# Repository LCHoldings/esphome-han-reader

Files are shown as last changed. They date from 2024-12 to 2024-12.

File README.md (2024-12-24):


[][contributors-url] [][forks-url] [][stars-url] [][issues-url]

<!-- PROJECT LOGO -->
<br />
<div align="center">
  <a href="https://github.com/lcholdings/esphome-han-reader">
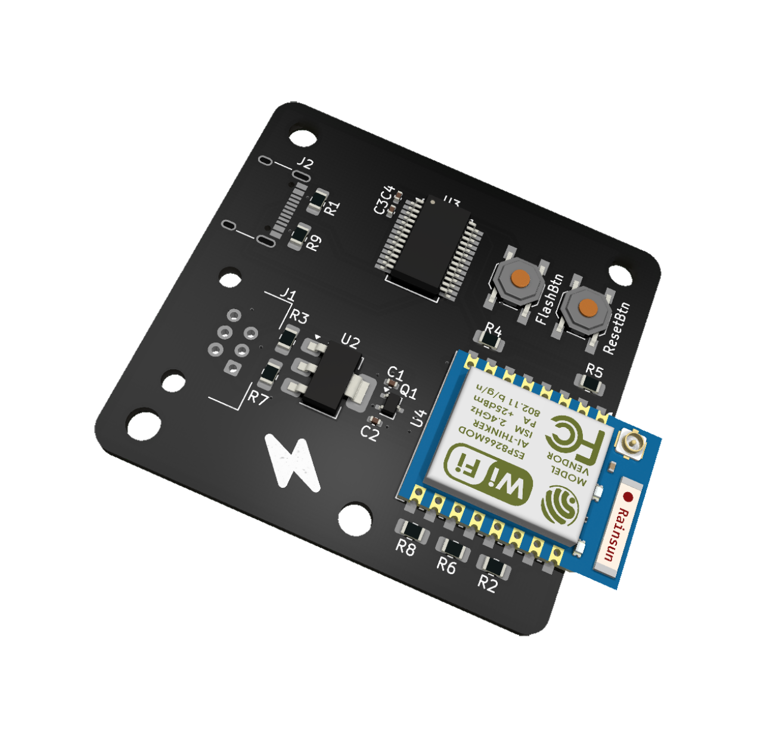
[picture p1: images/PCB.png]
    
  </a>

  <h3 align="center">ESP Home HAN Reader</h3>
  <p align="center">
    Get your power usage in realtime with extreme detail using the HAN-port.
    <br />
    <a href="https://github.com/hackclub/OnBoard/pull/1363">OnBoard PR</a>
    ·
    <a href="https://github.com/LCHoldings/esphome-han-reader/issues/new?labels=bug&template=bug-report---.md">Report Bug</a>
    ·
    <a href="https://github.com/LCHoldings/esphome-han-reader/fork">Fork Project</a>
  </p>
</div>

<!-- ABOUT THE PROJECT -->
## 📝 About The Project

In Sweden and Norway afaik we have a port on our electrical meters called the [HAN-port](https://github.com/u9n/hanporten) (Home Area Network), with this port you can get details about your power usage in almost realtime and with extreme detail compared to alternatives. I use Home Assistant in my home and we recently got our electrical meter replaced with one that has a HAN-port so I saw that as an perfect opportunity to learn some stuff and have fun.

<p align="right">(<a href="#readme-top">back to top</a>)</p>

### 🛠️ Made using

This section contains some of the most notable tools/libraries used in this project.

* 
* 

<p align="right">(<a href="#readme-top">back to top</a>)</p>

<!-- ROADMAP -->
## 🗺️ Roadmap

- [X] 🚢 Release project
- [X] 🖌️ Make ground fill
- [ ] 🤏 More compact design
- [ ] 📦 3D Printable Case
- [ ] 📡 Mouting for external antenna

<p align="right">(<a href="#readme-top">back to top</a>)</p>

<!-- CONTRIBUTING -->
## ⛑️ Contributing

Contributions are what make the open source community such an amazing place to learn, inspire, and create. Any contributions you make are **greatly appreciated**.

If you have a suggestion that would make the portfolio better, please fork the repo and create a pull request. You can also simply open an issue with the tag "enhancement".
Don't forget to give the project a star! Thanks!

1. Fork the Project
2. Change the project and add your files or changes (`git add *`)
3. Commit your Changes (`git commit -m 'Feat | Added XXXX to the XXX'`)
4. Push to the Branch (`git push`)
5. Open a Pull Request

### 🏆 Top contributors:

<a href="https://github.com/LCHoldings/esphome-han-reader/graphs/contributors">
  contrib.rocks image
</a>

<p align="right">(<a href="#readme-top">back to top</a>)</p>

<!-- CONTACT -->
## 💌 Contact

Lazyllama - [@Lazyllamaa](https://discord.com/users/754965470888722484) - me@lazyllama.xyz

Project Link: [https://github.com/lcholdings/esphome-han-reader](https://github.com/lcholdings/esphome-han-reader)

<p align="right">(<a href="#readme-top">back to top</a>)</p>

<!-- ACKNOWLEDGMENTS -->
## 🌟 Acknowledgments

Thanks to the following people for their help and inspiration:

* [Readme Template](https://github.com/othneildrew/Best-README-Template)
* [OnBoard](https://hackclub.com/onboard/)
* [Cyber](https://github.com/cyberdev-tech)
* [Hack Club](https://hackclub.com)
* [ESP Home P1 Reader](https://github.com/psvanstrom/esphome-p1reader)
<p align="right">(<a href="#readme-top">back to top</a>)</p>

<!-- MARKDOWN LINKS & IMAGES -->
<!-- https://www.markdownguide.org/basic-syntax/#reference-style-links -->
[contributors-shield]: https://img.shields.io/github/contributors/lcholdings/esphome-han-reader.svg?style=for-the-badge
[contributors-url]: https://github.com/lcholdings/esphome-han-reader/graphs/contributors
[forks-shield]: https://img.shields.io/github/forks/lcholdings/esphome-han-reader.svg?style=for-the-badge
[forks-url]: https://github.com/lcholdings/esphome-han-reader/network/members
[stars-shield]: https://img.shields.io/github/stars/lcholdings/esphome-han-reader.svg?style=for-the-badge
[stars-url]: https://github.com/lcholdings/esphome-han-reader/stargazers
[issues-shield]: https://img.shields.io/github/issues/lcholdings/esphome-han-reader.svg?style=for-the-badge
[issues-url]: https://github.com/lcholdings/esphome-han-reader/issues

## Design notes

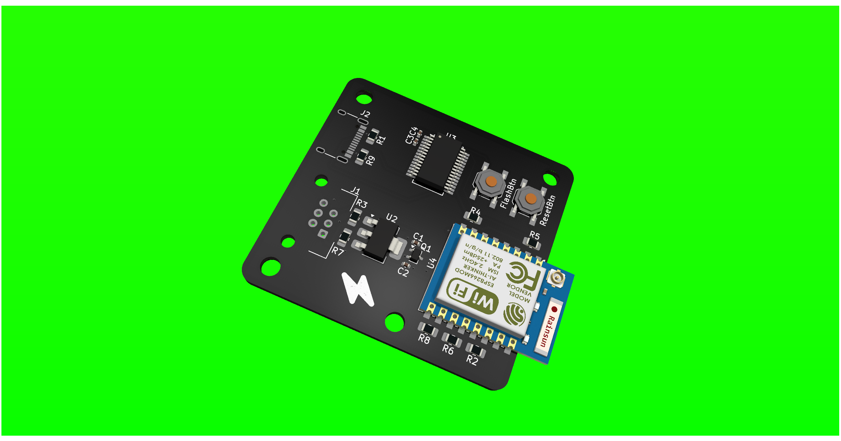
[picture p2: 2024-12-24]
esphome-han-reader.png

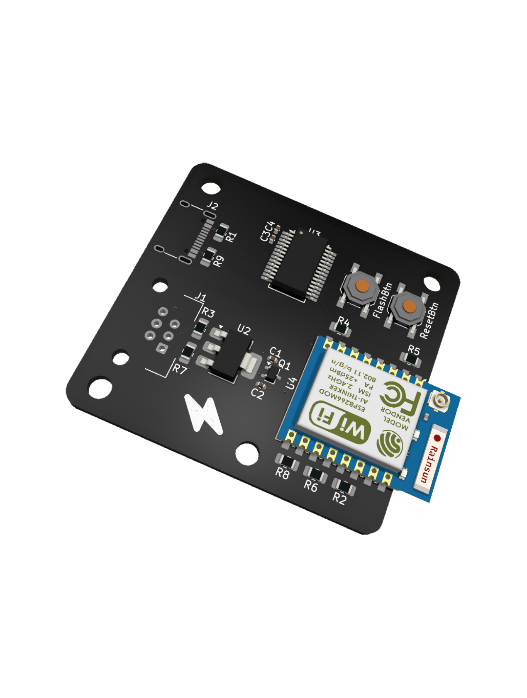
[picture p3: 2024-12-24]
images/highseas.png

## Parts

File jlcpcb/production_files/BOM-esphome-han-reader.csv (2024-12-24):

Comment | Designator | Footprint | LCSC | Quantity
0.1 µF | C3,C4 | C_0402_1005Metric | C1525 | 2
10K | R2,R4,R5,R6,R7,R8 | R_0805_2012Metric_Pad1.20x1.40mm_HandSolder | C17414 | 6
4K7 | R3 | R_0805_2012Metric_Pad1.20x1.40mm_HandSolder | C17673 | 1
5K1 | R1,R9 | R_0805_2012Metric_Pad1.20x1.40mm_HandSolder | C23186 | 2
TLV1117LV33DCYT | U2 | SOT-223-3_TabPin2 | C2877977 | 1
ResetBtn | SW1,SW2 | SW_SPST_TL3342 | C318884 | 2
YTC-TC16-473 | J2 | USB_C_Receptacle_XKB_U262-16XN-4BVC11 | C5329561 | 1
22uF | C1,C2 | C_0402_1005Metric | C5672 | 2
BC817W | Q1 | SOT-323_SC-70 | C75566 | 1
RJ12 | J1 | RJ12_DS1133-S60BPX | C77859 | 1
ESP-07 | U4 | ESP-07 | C82894 | 1
FT232RL | U3 | SSOP-28_5.3x10.2mm_P0.65mm | C8690 | 1

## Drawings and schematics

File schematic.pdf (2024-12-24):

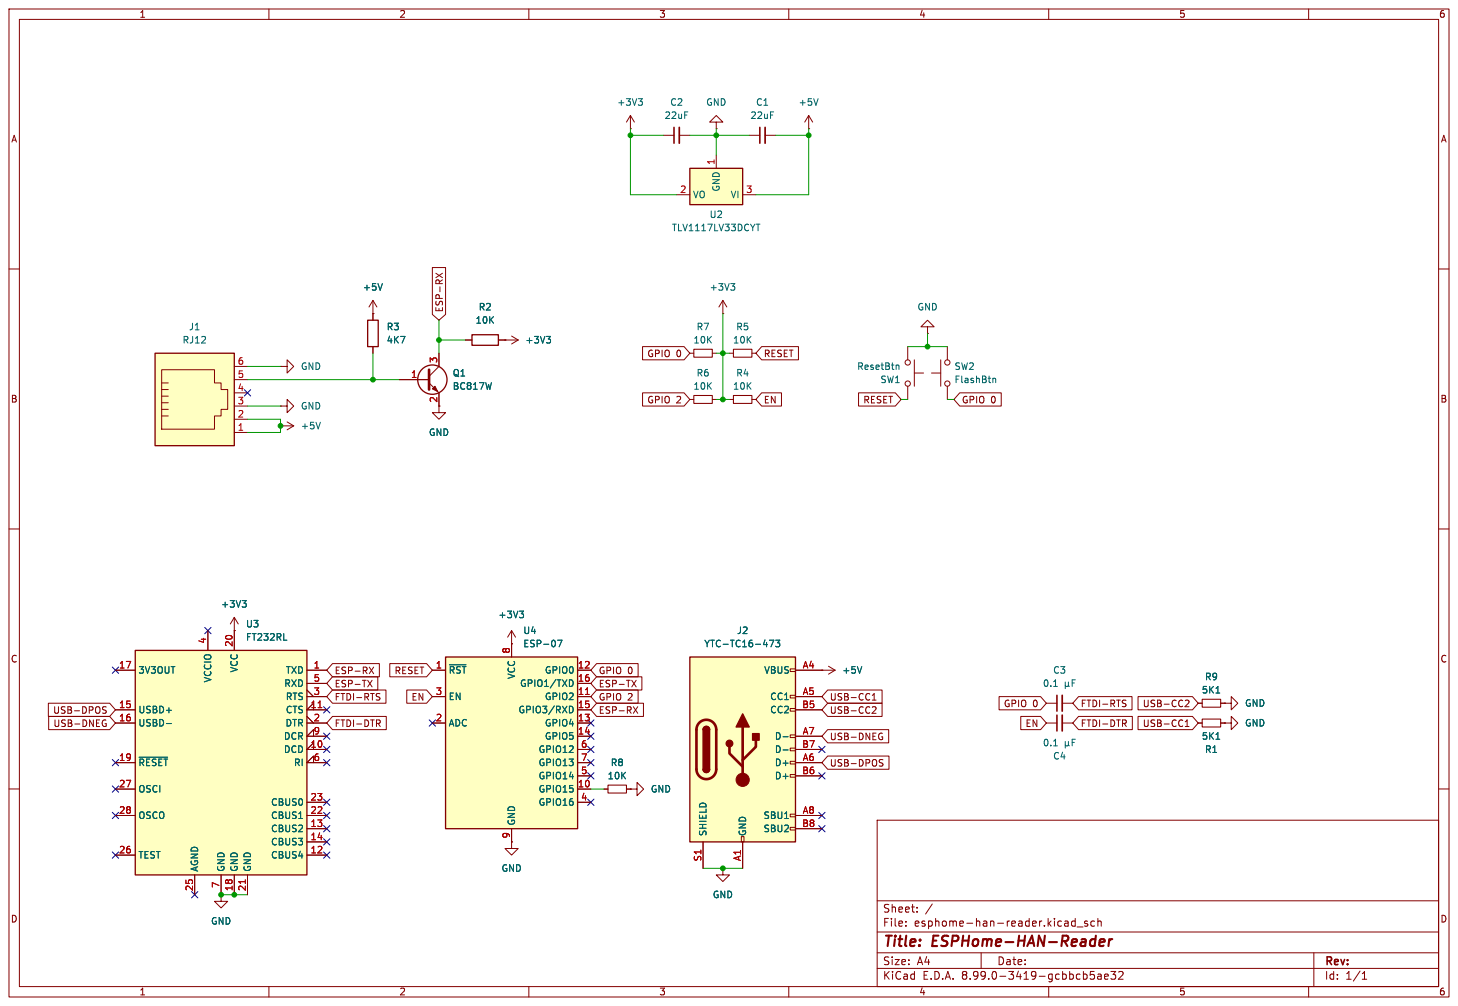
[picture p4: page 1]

7 VCC 20 GND 18 GND 21 TXD 1 RXD 5 RTS 3 CTS 11 DTR 2 DCR 9 DCD 10 RI 6 CBUS0 23 CBUS1 22 CBUS2 13 CBUS3 14 CBUS4 12 U3 FT232RL R6

7 VCC 20 GND 18 GND 21 TXD 1 RXD 5 RTS 3 CTS 11 DTR 2 DCR 9 DCD 10 RI 6 CBUS0 23 CBUS1 22 CBUS2 13 CBUS3 14 CBUS4 12 U4ESP-07 ~{RST} 1 EN 3 ADC 2 VCC

9 GPIO0 12 GPIO1/TXD 16 GPIO2 11 GPIO3/RXD 15 GPIO4 13 GPIO5 14 GPIO12 6 GPIO13 7 GPIO14 5 GPIO15 10 GPIO16 4 U4ESP-07 GND SHIELD S1 GND A1 VBUS A4 CC1 A5 CC2 B5 D- A7 D- B7 D+ A6 D+ B6 SBU1 A8 SBU2 B8

9 GPIO0 12 GPIO1/TXD 16 GPIO2 11 GPIO3/RXD 15 GPIO4 13 GPIO5 14 GPIO12 6 GPIO13 7 GPIO14 5 GPIO15 10 GPIO16 4 GND GND

Id: 1/1 Title: ESPHome-HAN-Reader File: esphome-han-reader.kicad_sch Sheet: /

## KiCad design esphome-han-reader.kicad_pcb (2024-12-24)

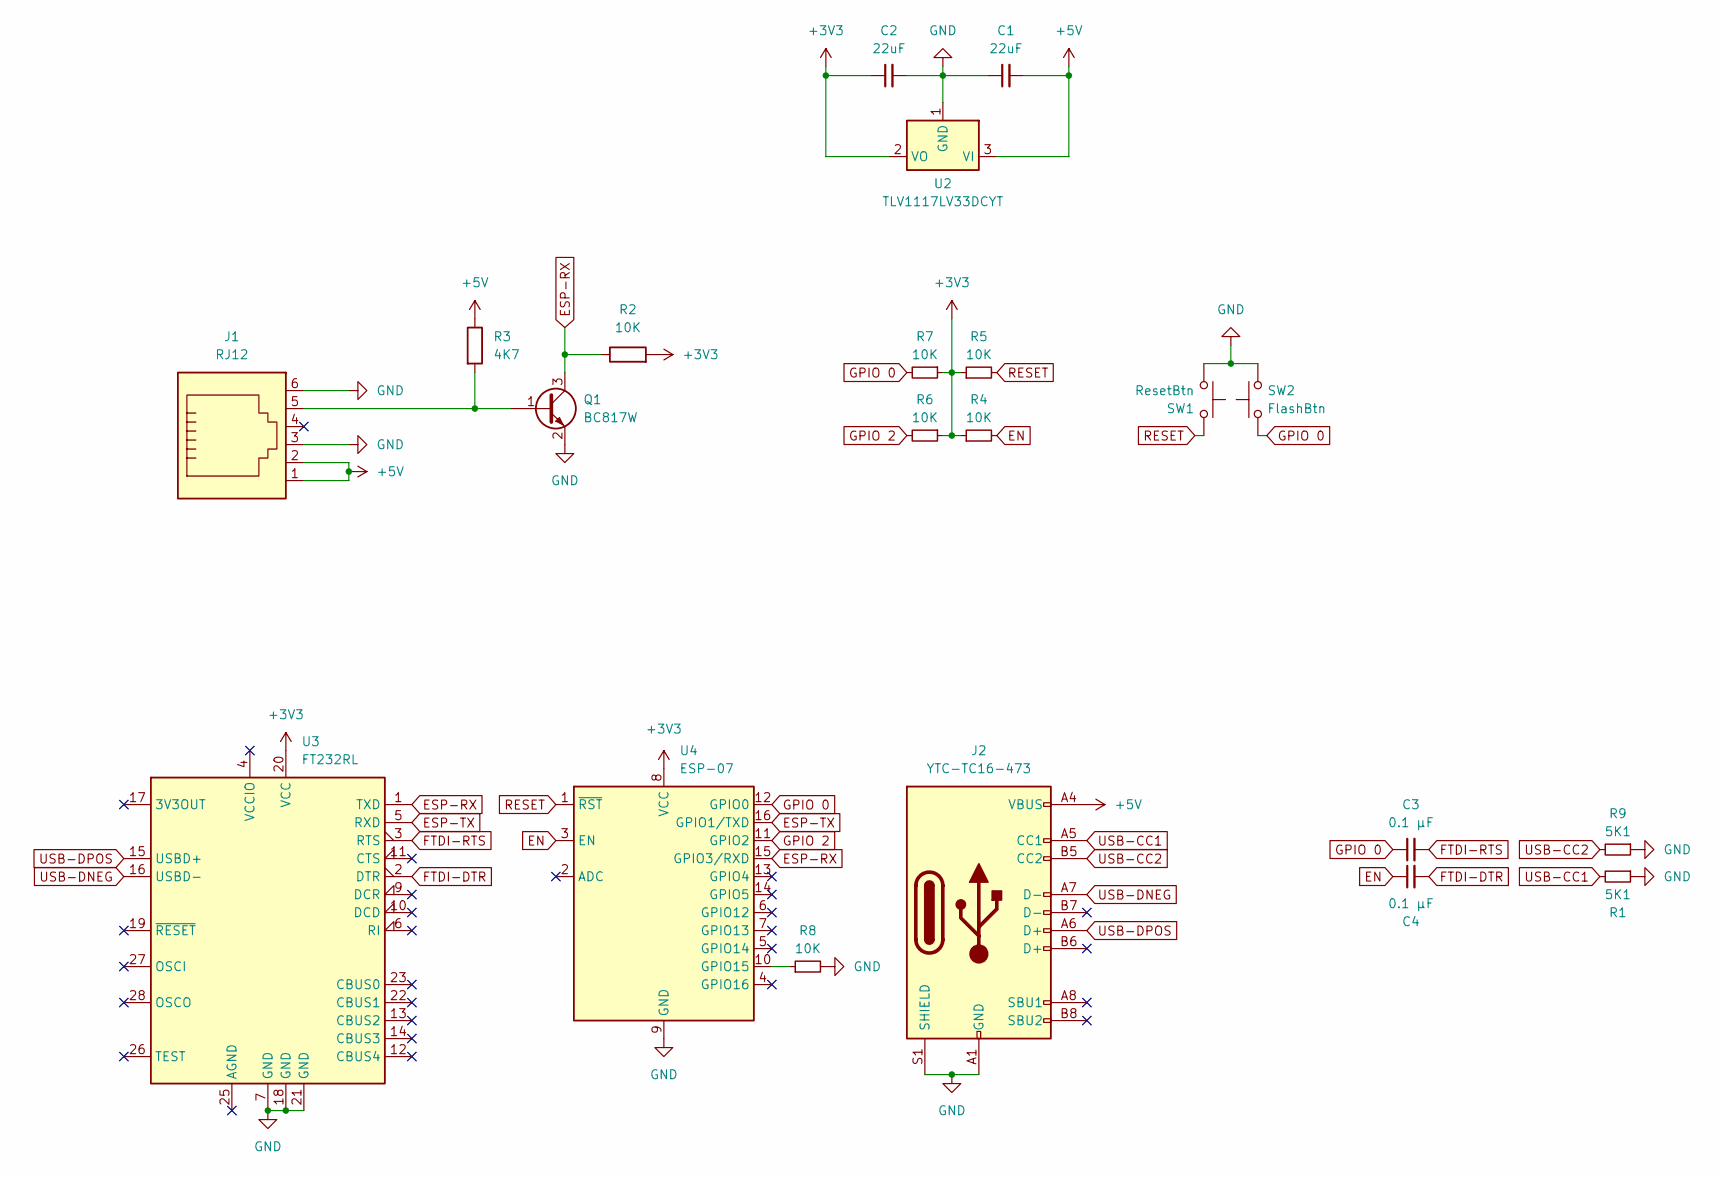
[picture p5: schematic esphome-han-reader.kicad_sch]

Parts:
C1, C2: 22uF; C_0402_1005Metric
C3, C4: 0.1 µF; C_0402_1005Metric
J1: RJ12; RJ12_DS1133-S60BPX
J2: YTC-TC16-473; USB_C_Receptacle_XKB_U262-16XN-4BVC11
Q1: BC817W; SOT-323_SC-70
R1, R9: 5K1; R_0805_2012Metric_Pad1.20x1.40mm_HandSolder
R2, R4, R5, R6, R7, R8: 10K; R_0805_2012Metric_Pad1.20x1.40mm_HandSolder
R3: 4K7; R_0805_2012Metric_Pad1.20x1.40mm_HandSolder
SW1: ResetBtn; SW_SPST_TL3342
SW2: FlashBtn; SW_SPST_TL3342
U2: TLV1117LV33DCYT; SOT-223-3_TabPin2
U3: FT232RL; SSOP-28_5.3x10.2mm_P0.65mm
U4: ESP-07

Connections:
+3V3: C2.1, R2.2, R4.1, R5.1, R6.1, R7.1, U2.2 (VO), U3.20 (VCC), U4.8 (VCC)
+5V: C1.2, J1.1, J1.2, J2.A4 (VBUS), J2.A9 (VBUS), J2.B4 (VBUS), J2.B9 (VBUS), R3.1, U2.3 (VI)
EN: C4.1, R4.2, U4.3 (EN)
ESP-RX: Q1.3 (C), R2.1, U3.1 (TXD), U4.15 (GPIO3/RXD)
ESP-TX: U3.5 (RXD), U4.16 (GPIO1/TXD)
FTDI-DTR: C4.2, U3.2 (DTR)
FTDI-RTS: C3.2, U3.3 (RTS)
GND: C1.1, C2.2, J1.3, J1.6, J2.A1 (GND), J2.A12 (GND), J2.B1 (GND), J2.B12 (GND), J2.S1 (SHIELD), Q1.2 (E), R1.1, R8.2, R9.1, SW1.1, SW2.2, U2.1 (GND), U3.7 (GND), U3.18 (GND), U3.21 (GND), U4.9 (GND)
GPIO 0: C3.1, R7.2, SW2.1, U4.12 (GPIO0)
GPIO 2: R6.2, U4.11 (GPIO2)
unnamed: J1.5, Q1.1 (B), R3.2
unnamed: R8.1, U4.10 (GPIO15)
RESET: R5.2, SW1.2, U4.1 (~RST)
USB-CC1: J2.A5 (CC1), R1.2
USB-CC2: J2.B5 (CC2), R9.2
USB-DNEG: J2.A7 (D-), U3.16 (USBD-)
USB-DPOS: J2.A6 (D+), U3.15 (USBD+)

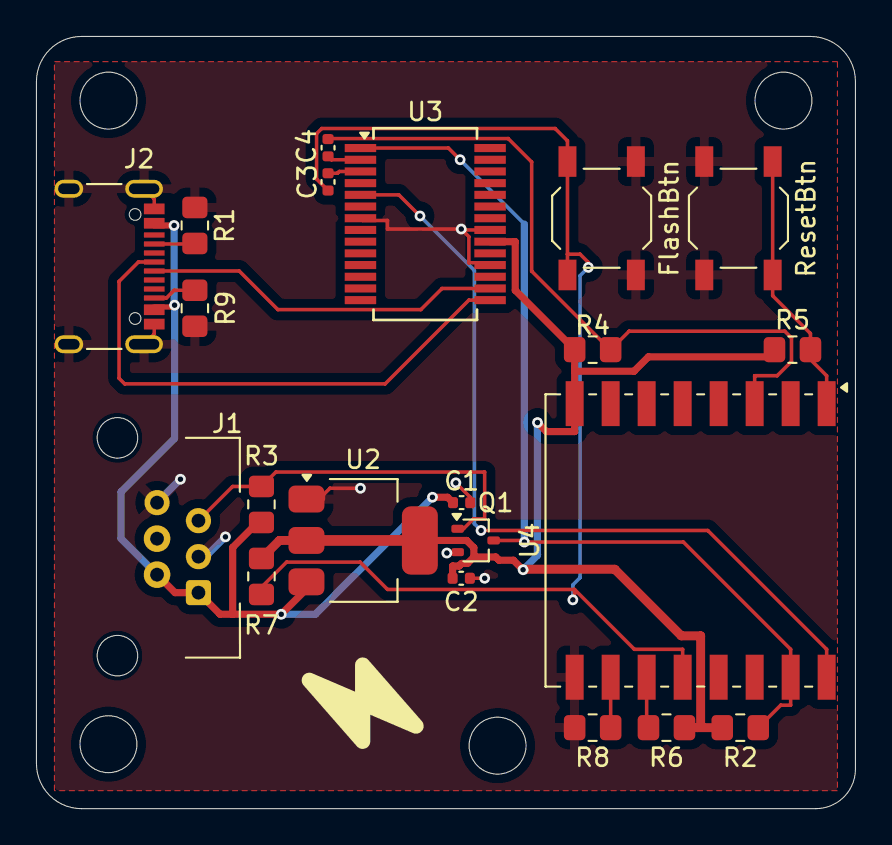
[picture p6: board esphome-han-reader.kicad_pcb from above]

Board: 2 copper layers, 45.5 x 42.9 mm, 21 parts (0 on the bottom side), 17 nets.

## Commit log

2024-12-19 feat: I'm cooking 🔥
    TODO: add interferance remover switch and make 3d model case.
    [esphome-han-reader 2.kicad_sch, esphome-han-reader.kicad_pcb, esphome-han-reader.kicad_sch]
2024-12-21 feat: Final Rev??
    [BOM-esphome-han-reader.csv, esphome-han-reader.kicad_pcb, esphome-han-reader.kicad_sch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]
2024-12-21 fix: make high seas readme render correctly 🧰
2024-12-21 feat: Gerber file 📁
2024-12-23 feat: new design, new caps and onboard programmer.
    [BOM-esphome-han-reader.csv, esphome-han-reader.kicad_sch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]
2024-12-24 feat: actually final revision. PR merged and PCBs ordered.
    [BOM-esphome-han-reader.csv, esphome-han-reader.kicad_pcb]
2024-12-24 feat: PCB Image
2024-12-24 feat: highseas image 🚢
